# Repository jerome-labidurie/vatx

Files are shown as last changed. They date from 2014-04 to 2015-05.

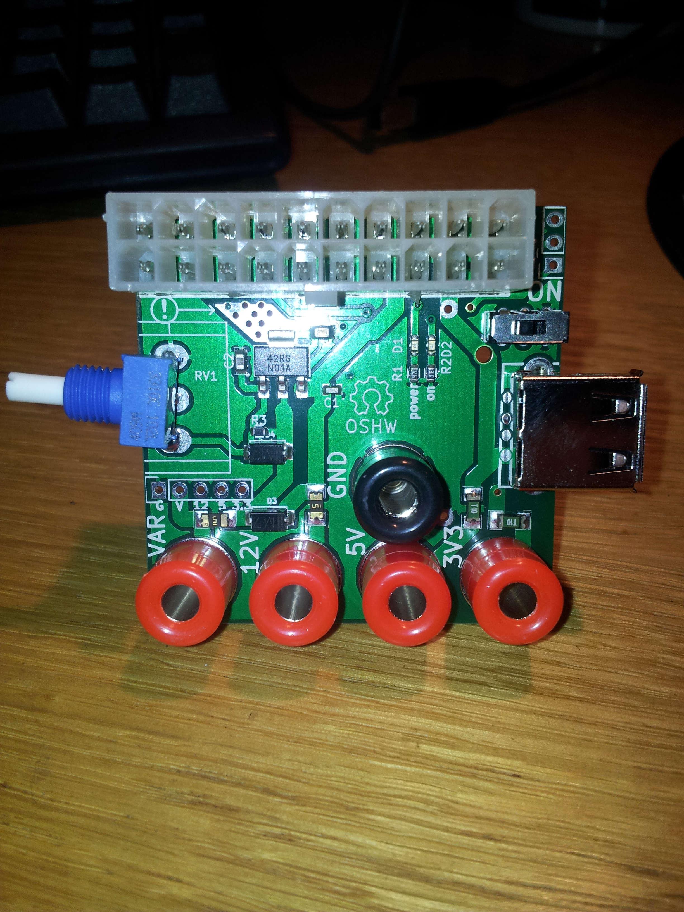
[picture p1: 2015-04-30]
pictures/vatx_proto_0_2.jpg

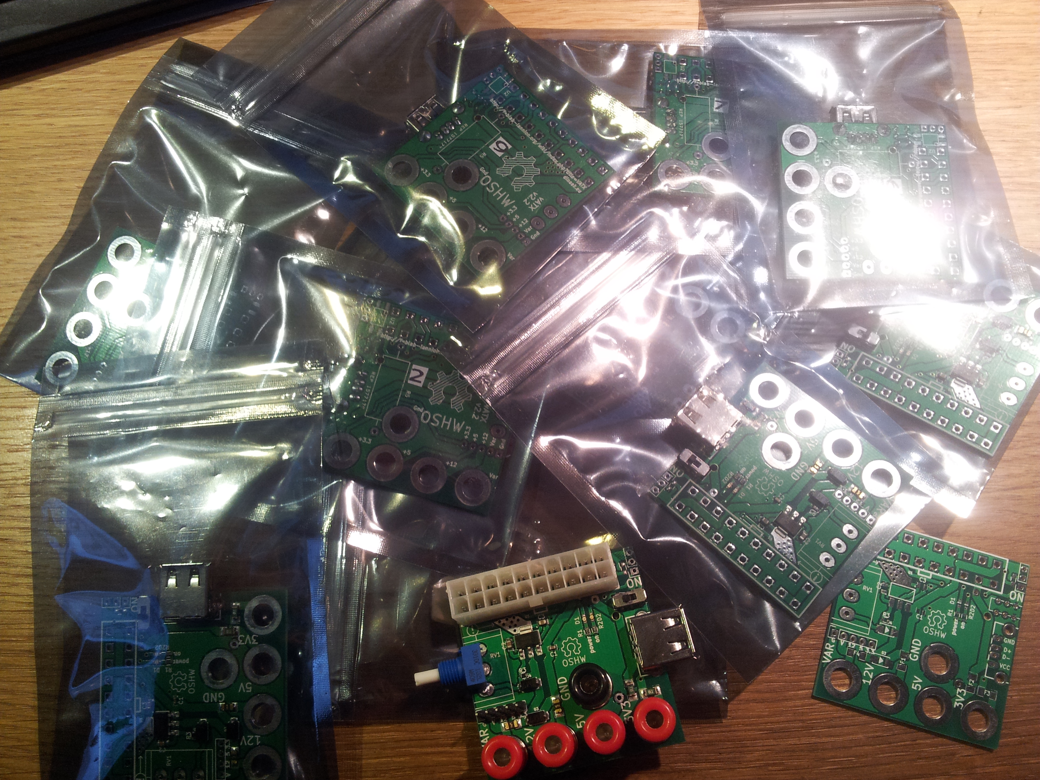
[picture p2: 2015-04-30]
pictures/vatx_proto_0_0.jpg

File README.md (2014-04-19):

Simple breakoutboard to use an ATX PSU as variable PSU
======================================================

* Goal is to use a un-modified ATX PSU.
* mostly one side-PCB for very simple creation
* Use banana plugs for every voltage
* Use LM317 for 1.5A variable voltage (~ 3-11V)
* USB connector for particular devices
* StandBy/Power leds
* OpenHardware CC:BY-SA http://creativecommons.org/licenses/by-sa/3.0/

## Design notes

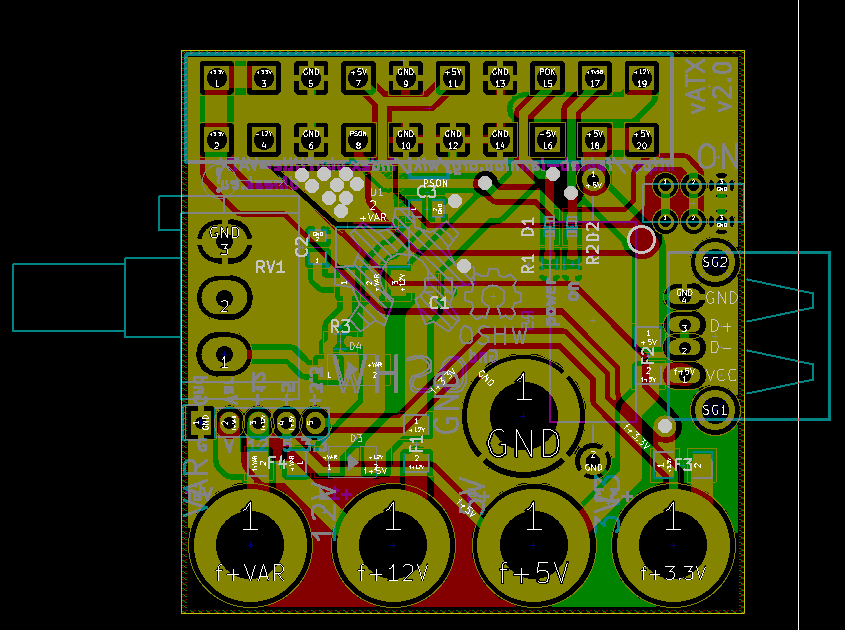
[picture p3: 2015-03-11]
pictures/vatx_pcb_v2.0.png

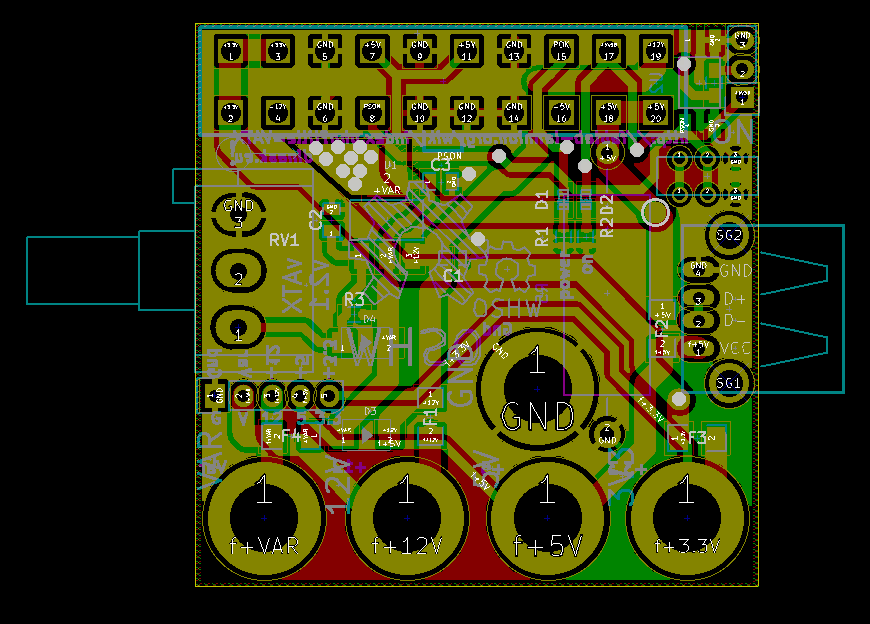
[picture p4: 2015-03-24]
pictures/vatx_pcb_v2.1.png

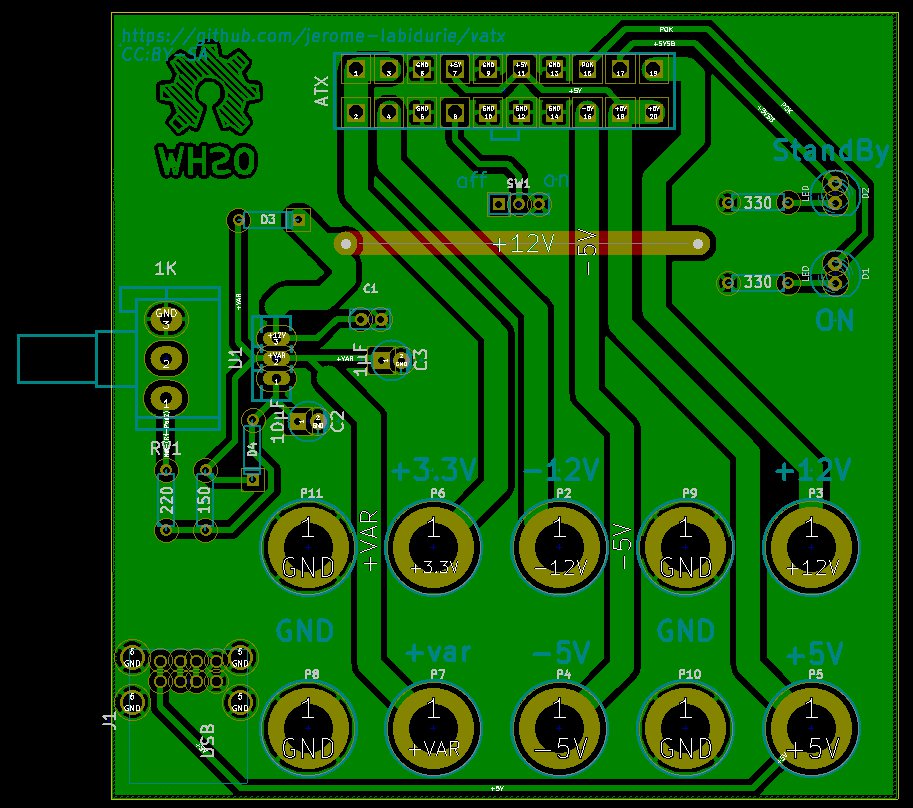
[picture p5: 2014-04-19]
pictures/vatx_pcb_v1.0.jpg

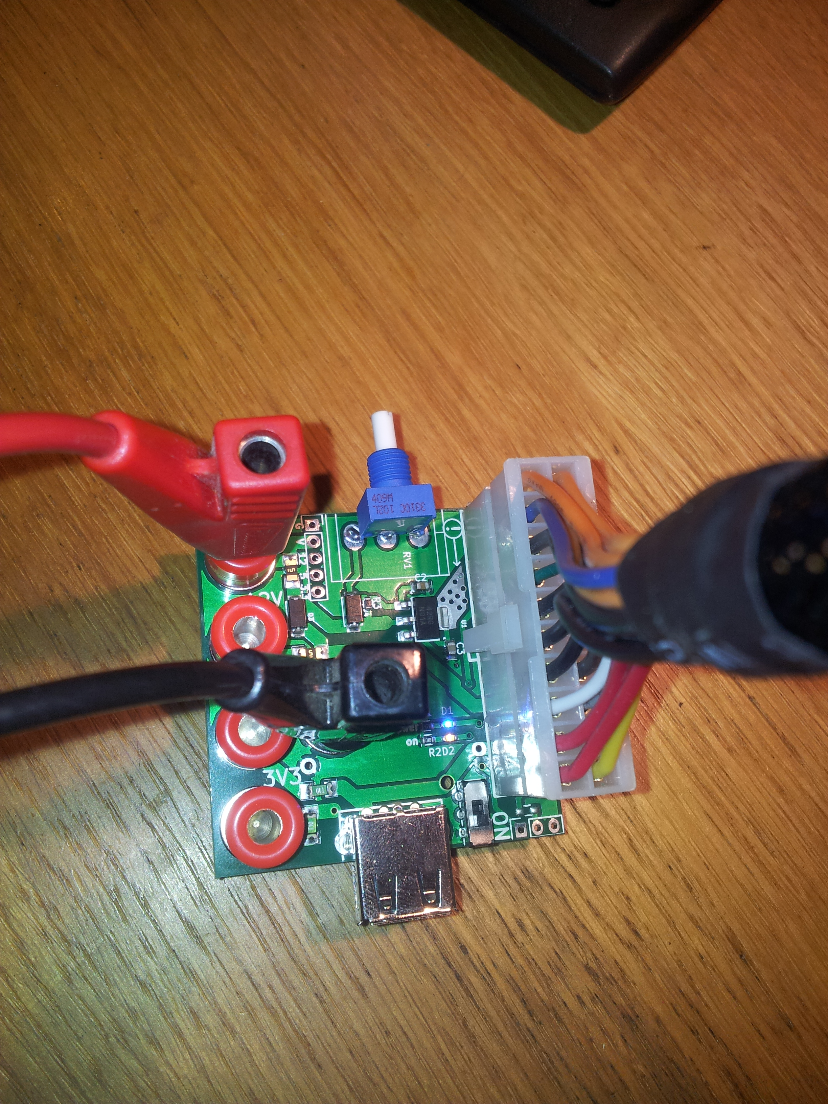
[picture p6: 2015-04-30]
pictures/vatx_proto_0_1.jpg

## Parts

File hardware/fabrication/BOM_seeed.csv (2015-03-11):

OPL SKU | Qty | Parts
310030006 | 1 | U1
320010007 | 1 | J1
0100020P1 | 1 | C1
0100080P1 | 1 | C2
0100440P1 | 1 | C3
0330060P1 | 1 | D1
0330050P1 | 1 | D2
307010013 | 2 | F1;F4
0900020P1 | 2 | F2;F3
301010088 | 1 | R1
0011090P1 | 1 | R2
301010090 | 1 | R3
0300040P1 | 2 | D3;D4
3010010P1 | 1 | SW1

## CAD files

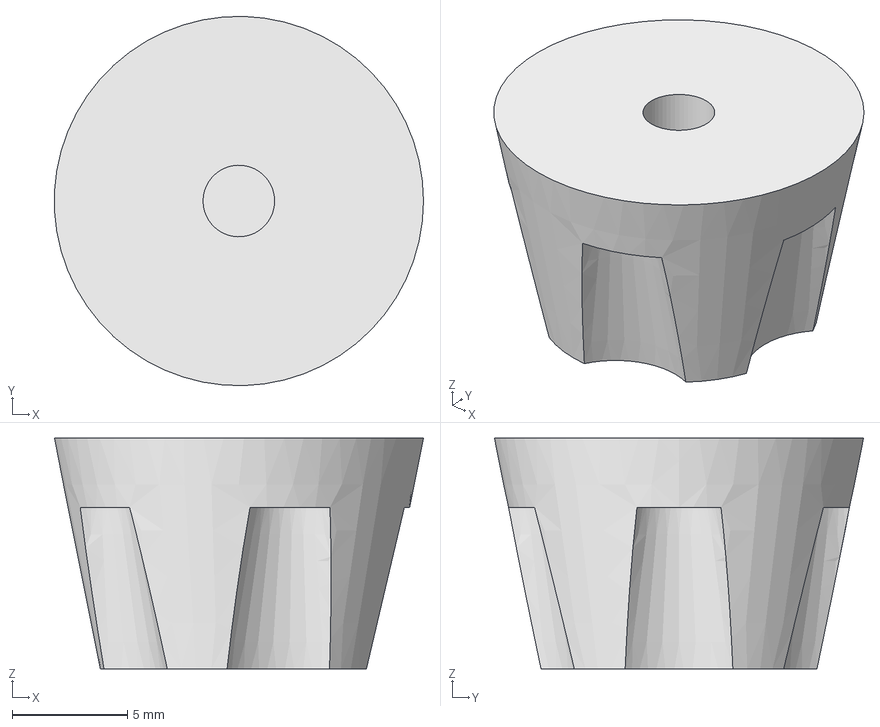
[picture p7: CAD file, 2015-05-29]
box/knob.fcstd
16.0 x 16.0 x 10.0 mm

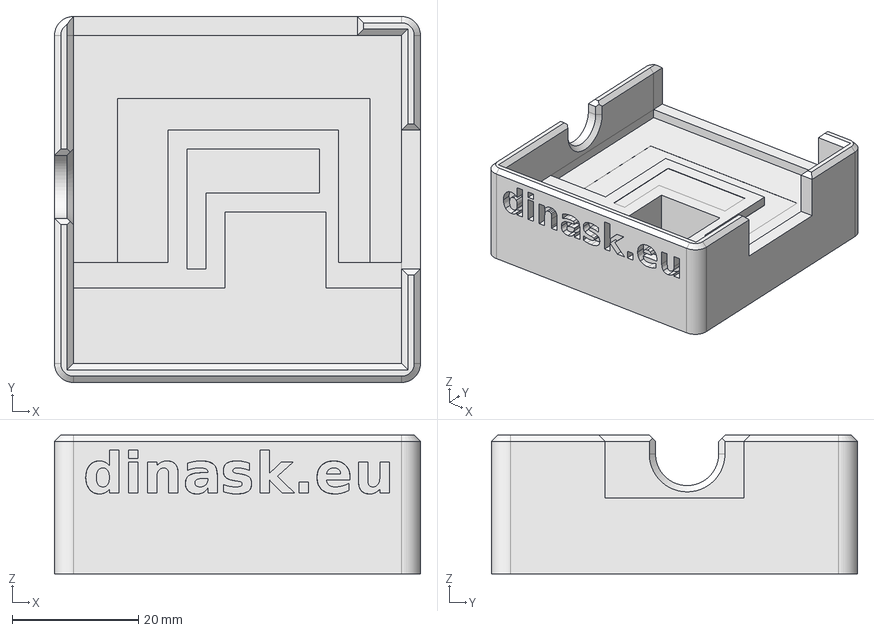
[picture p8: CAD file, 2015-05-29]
box/v2.2.FCstd
58.0 x 58.0 x 22.0 mm

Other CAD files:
box/knob.stl
box/v2.2.stl

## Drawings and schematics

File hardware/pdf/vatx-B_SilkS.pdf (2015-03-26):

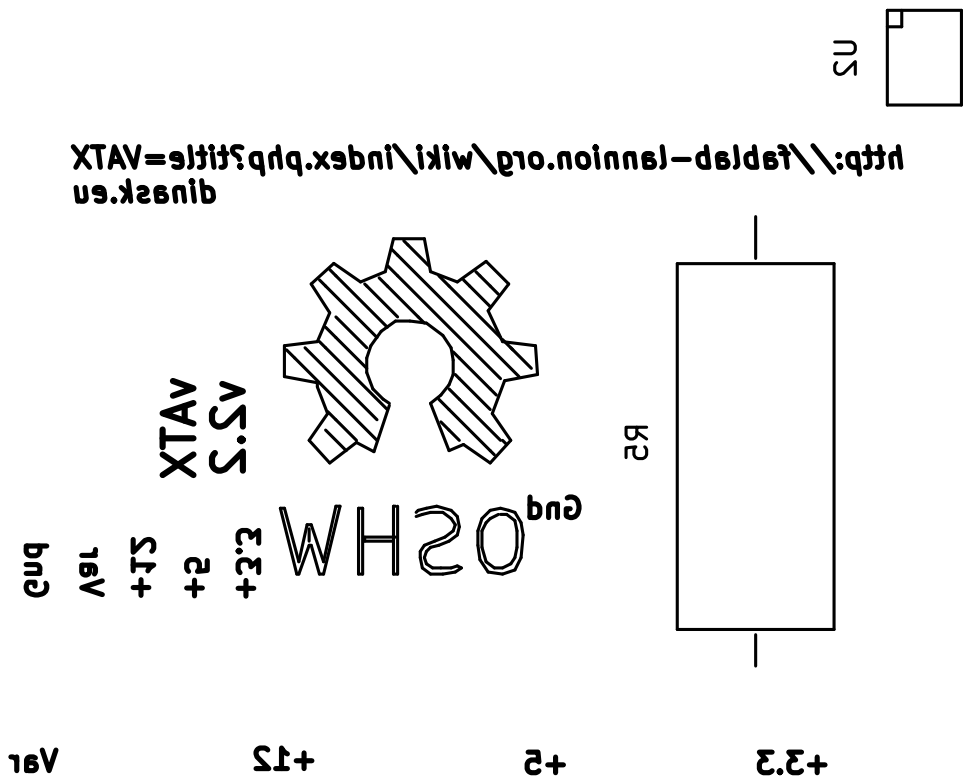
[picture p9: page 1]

http://fablab-lannion.org/wiki/index.php?title=VATX

Var +12 +5 +3.3 Gnd Gnd Var +12 +5+3.3 vATX v2.2

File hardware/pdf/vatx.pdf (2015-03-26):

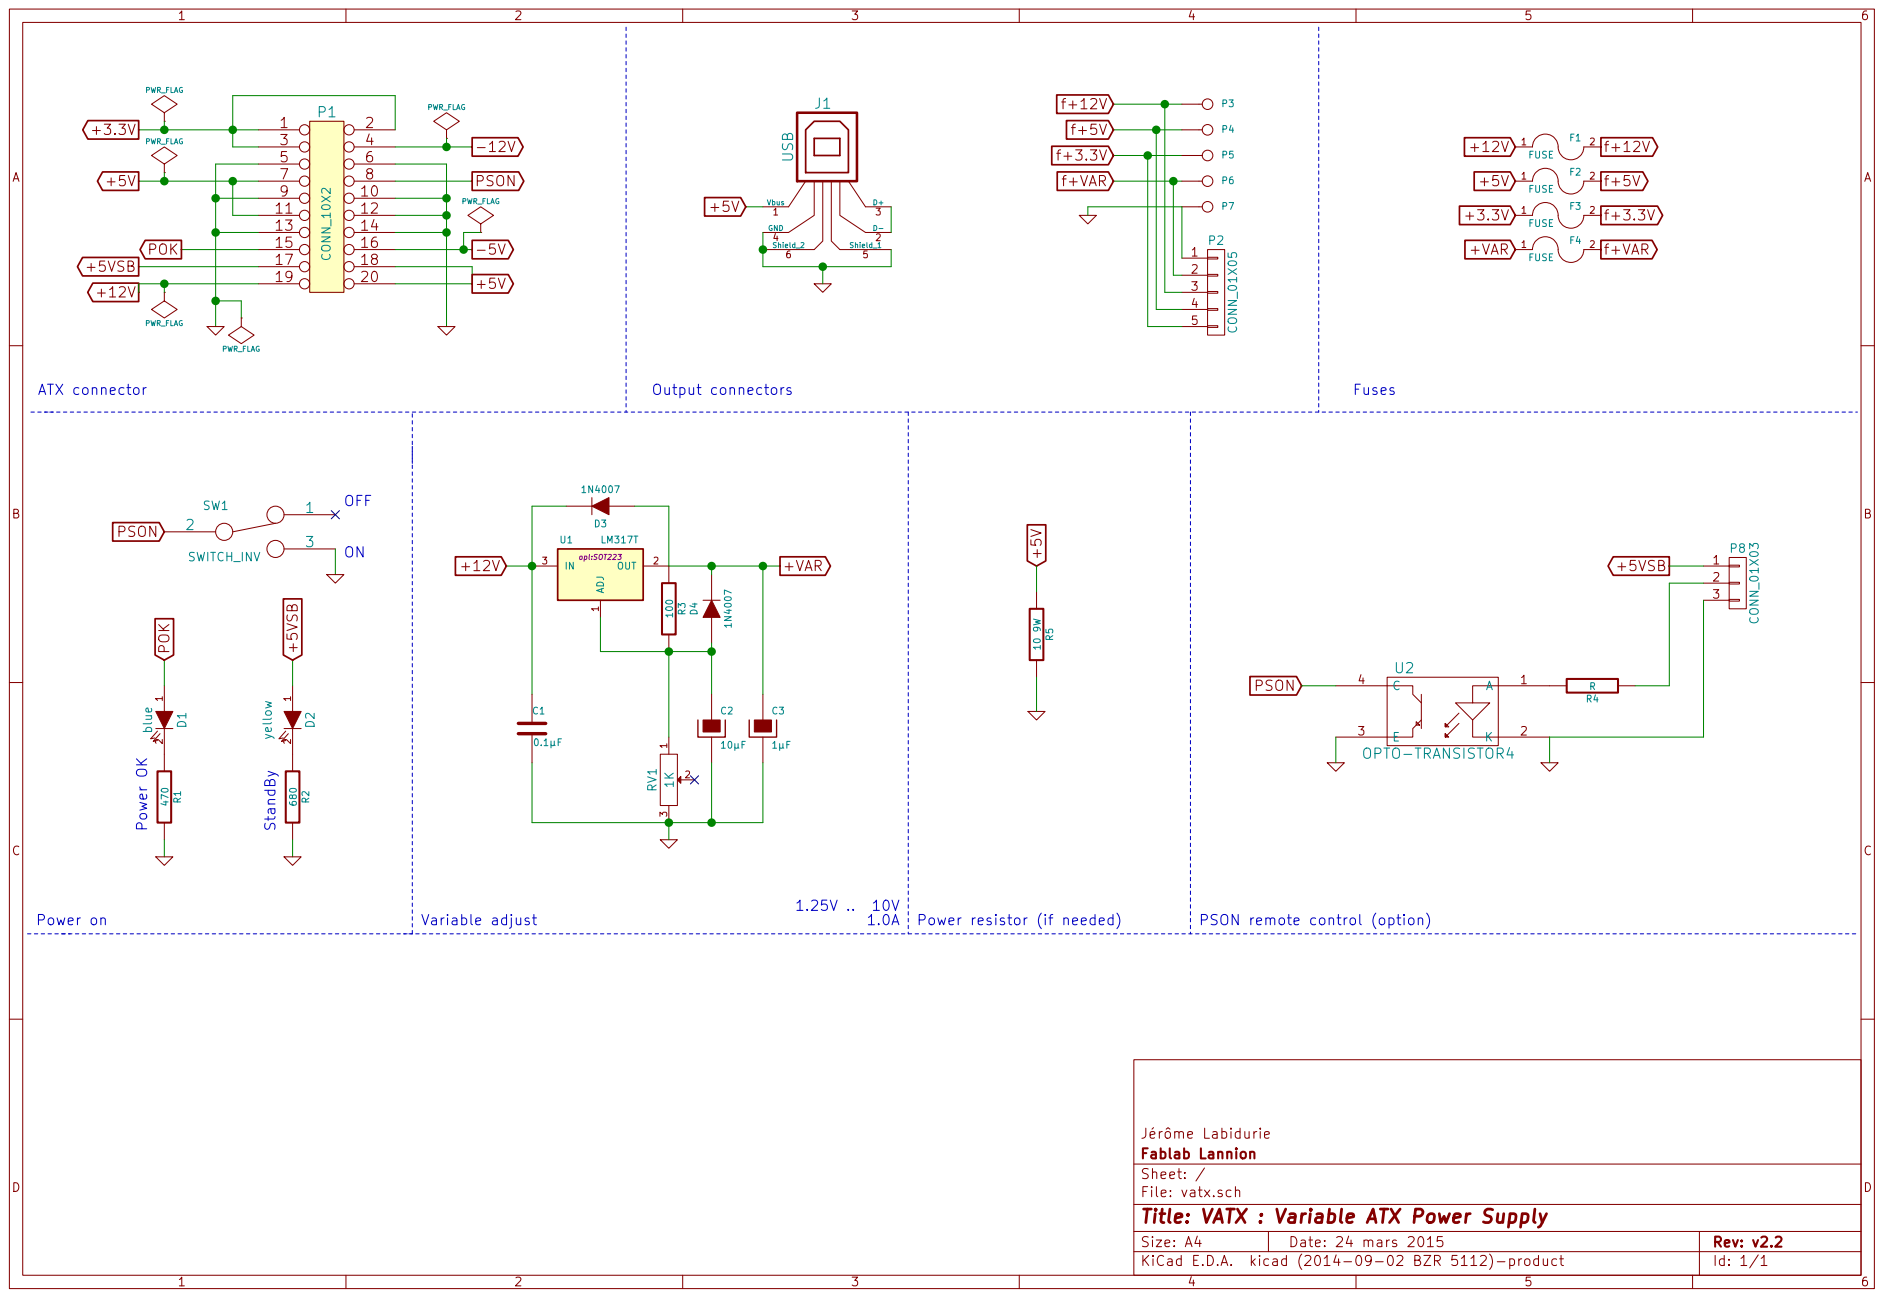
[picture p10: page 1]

1 2 D2 yellow 680 R2 +5VSB StandBy ADJ 1 OUT 2

1 2 D1 blue 470 R1 POK Power OK

Power resistor (if needed)

PSON remote control (option)

Jérôme Labidurie
File: vatx.sch Sheet: / Fablab Lannion

Id: 1/1 Title: VATX : Variable ATX Power Supply

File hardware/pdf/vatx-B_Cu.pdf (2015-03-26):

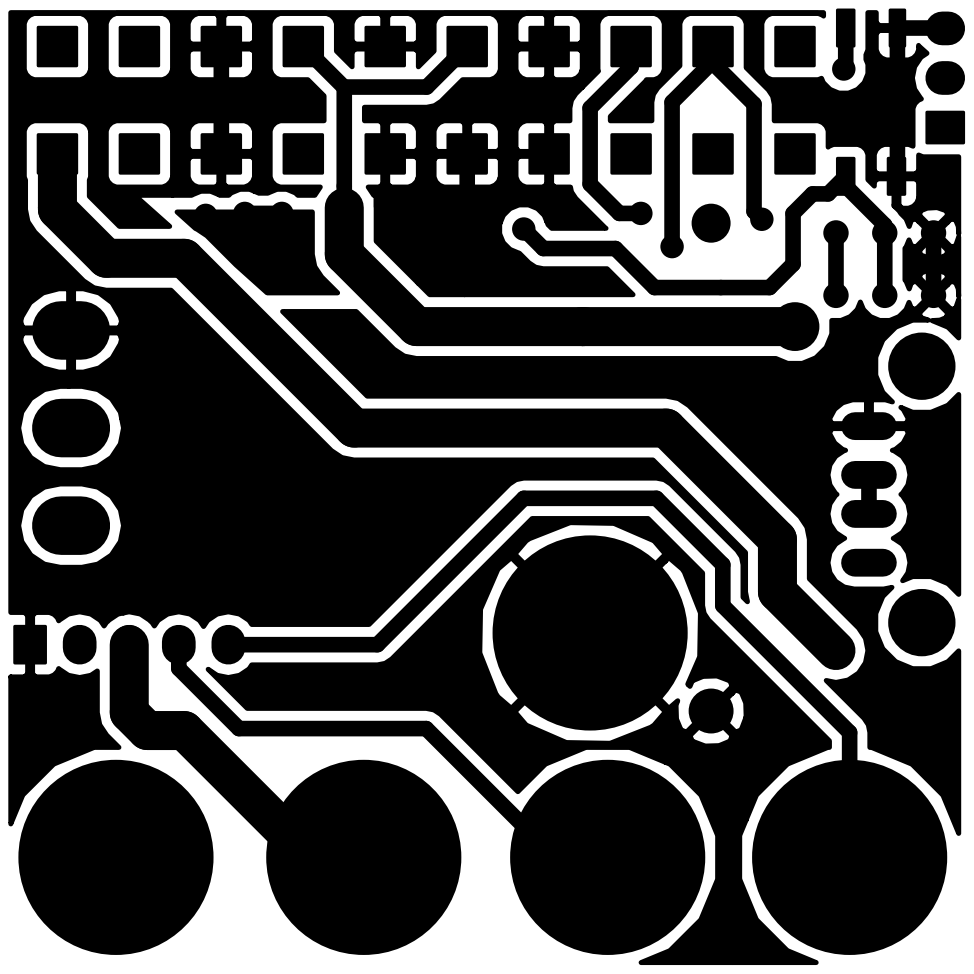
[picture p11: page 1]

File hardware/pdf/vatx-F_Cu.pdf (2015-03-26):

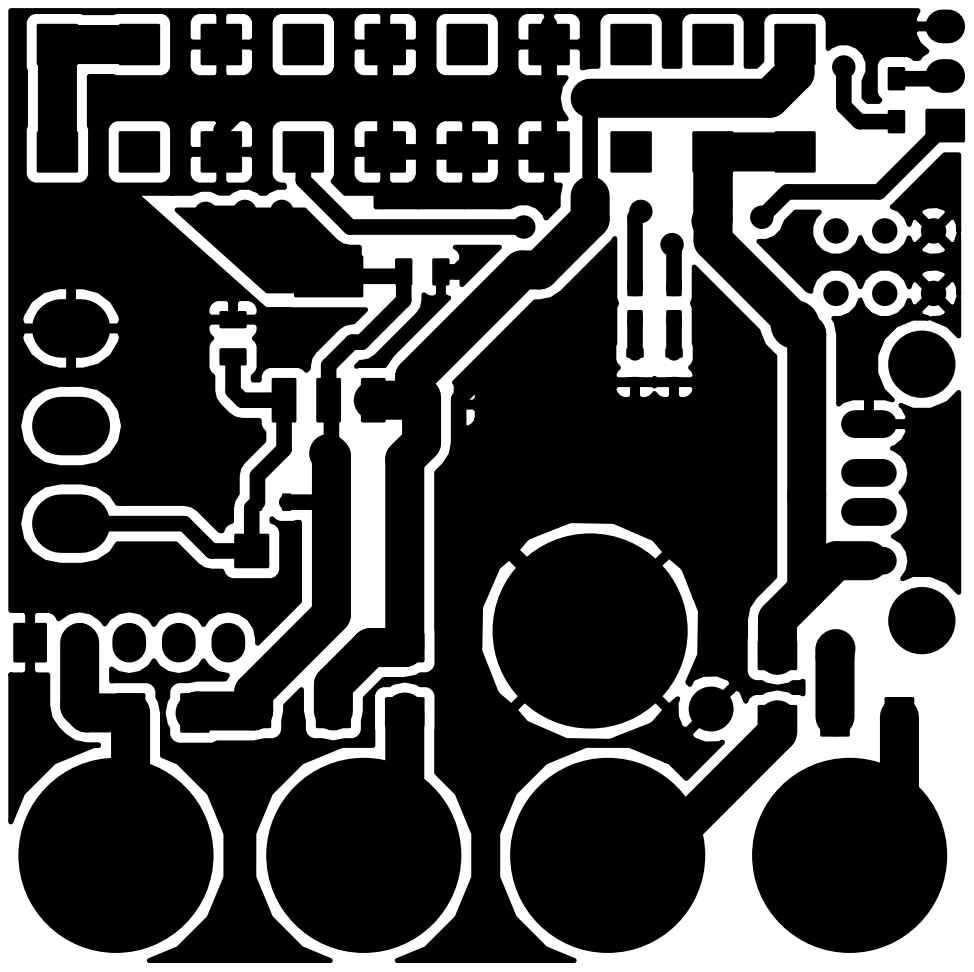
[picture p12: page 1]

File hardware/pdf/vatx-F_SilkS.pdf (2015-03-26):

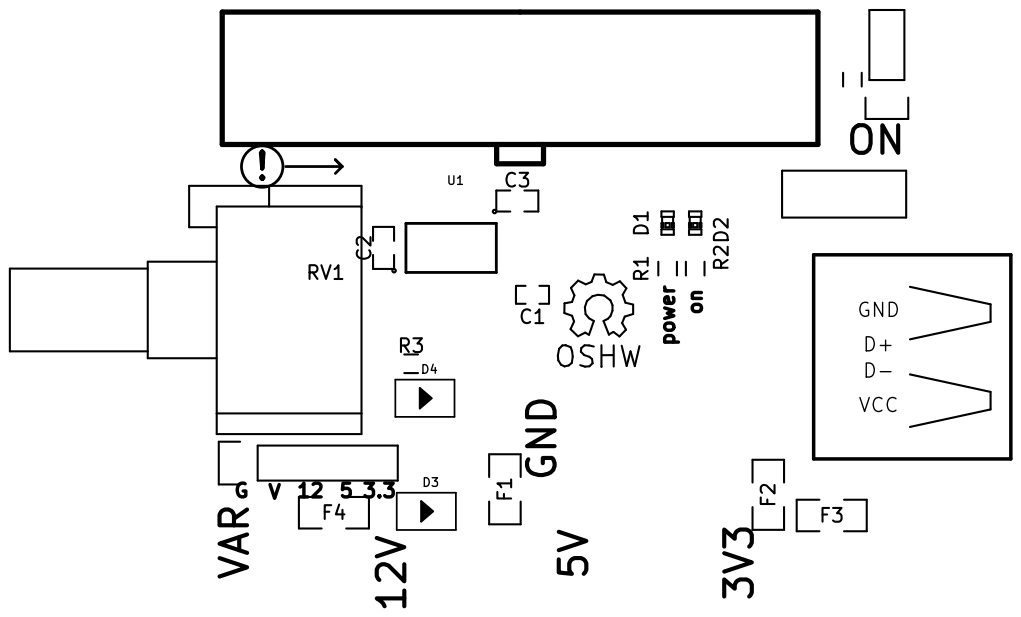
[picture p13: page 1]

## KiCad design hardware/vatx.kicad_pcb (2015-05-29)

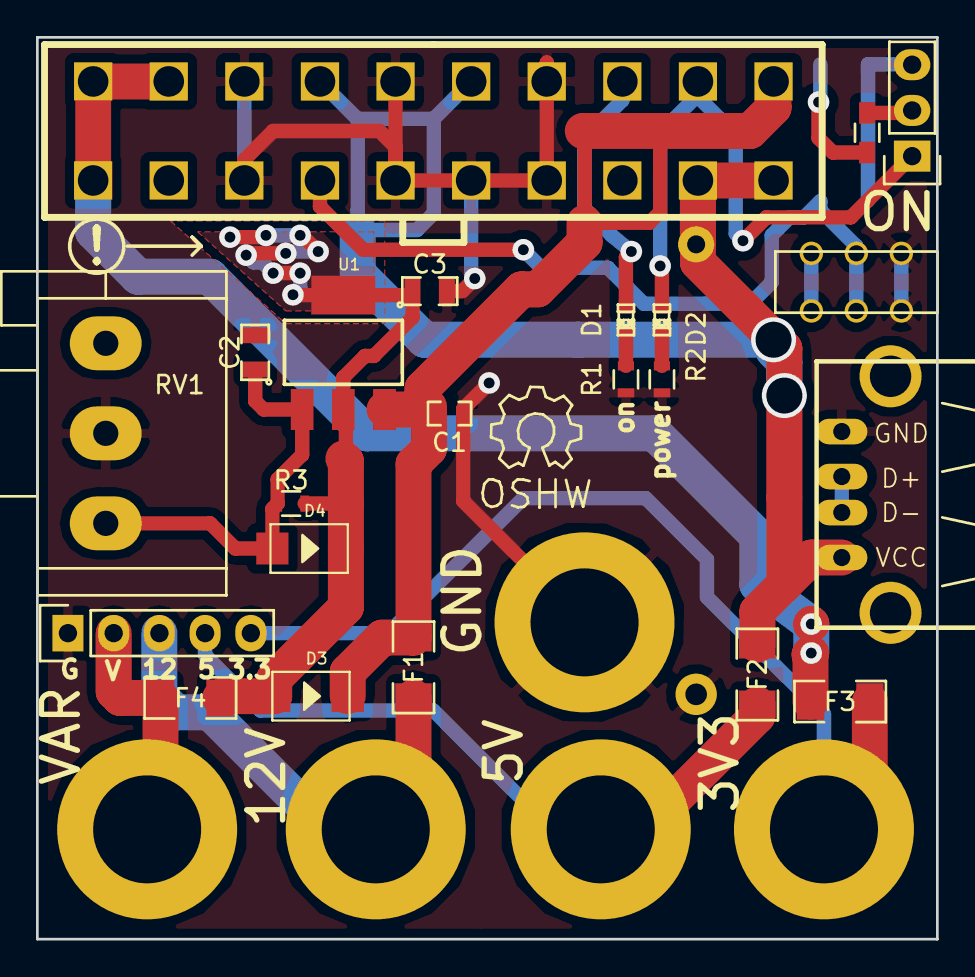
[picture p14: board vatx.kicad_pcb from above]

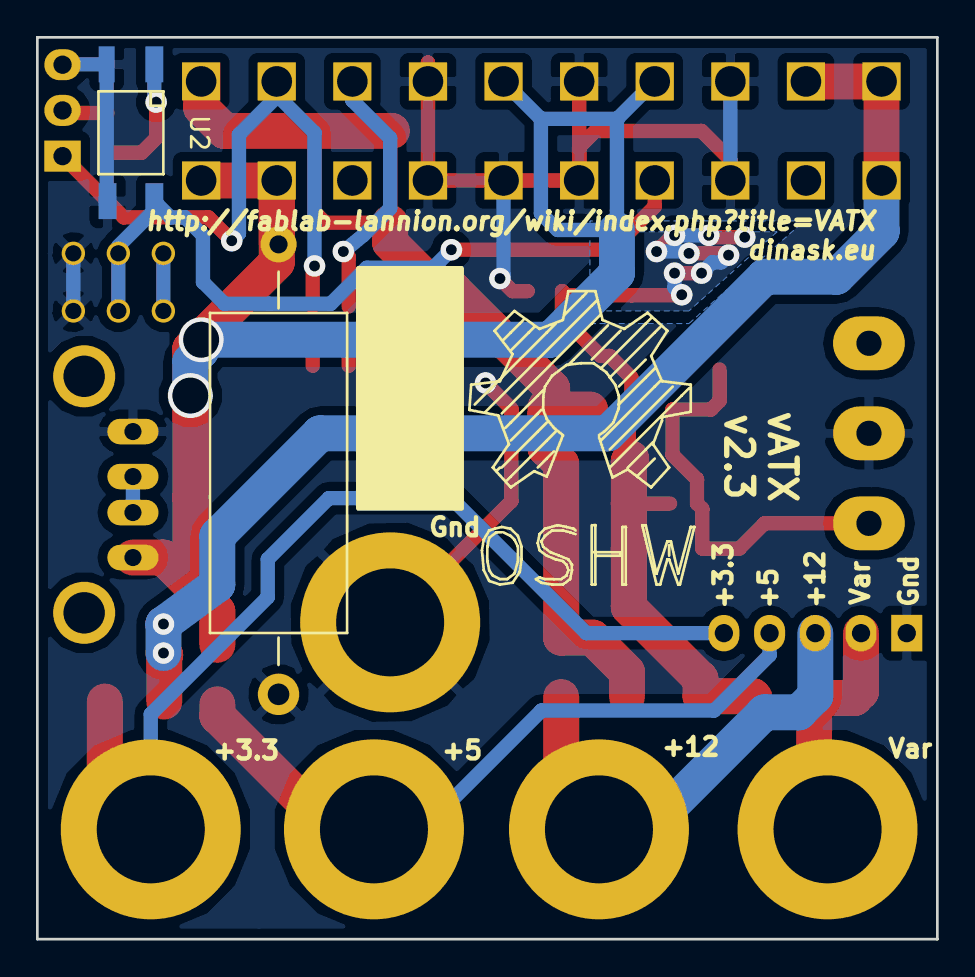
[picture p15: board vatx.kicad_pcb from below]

Board: 2 copper layers, 50.0 x 50.1 mm, 31 parts (3 on the bottom side), 18 nets.

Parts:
C1: 0.1µF; SMD-0603_c
C2: 10µF; SMD-0805
C3: 1µF; SMD-0805
D1: blue; LED-0603
D2: yellow; LED-0603
D3, D4: 1N4007; DO-214AC
F1, F2, F3, F4: FUSE; SMD-1206
J1: USB; 4P-2.0-90D
P1: CONN_10X2; ATX_NON_90DEG
P2: CONN_01X05; Pin_Header_Straight_1x05
P3, P4, P5, P6, P7: CONN_1; Banana_single_6mmDrill
P8: CONN_01X03; Pin_Header_Straight_1x03
R1: 470; R_0603
R2: 680; R_0603
R3: 100; R_0603
R4: R; R_0603_HandSoldering
R5: 10 9W; Resistor_Horizontal_RM25mm
RV1: 1K; Potentiometer_Alps-RK16-single_largePads
SW1: SWITCH_INV; TS-1101F
Symbol_OSHW-Logo_SilkScreen: VAL**; Symbol_OSHW-Logo_SilkScreen
Symbol_OSHW-Logo_SilkScreen_BIG: VAL**; Symbol_OSHW-Logo_SilkScreen_BIG
U1: LM317T; SOT223
U2: OPTO-TRANSISTOR4; Optocoupler_SMD_HandSoldering_KPC357_LTV35x_PC357_SingleCha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

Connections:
+3.3V: F3.1, P1.1, P1.2, P1.3
+5V: F2.1, J1.1, P1.7, P1.11, P1.18, P1.20, R5.1
+5VSB: D2.1, P1.17, P8.1
+12V: C1.1, D3.2, F1.1, P1.19, U1.3
+VAR: C3.1, D3.1, D4.2, F4.1, R3.1, U1.2
GND: C1.2, C2.2, C3.2, J1.4, P1.5, P1.6, P1.9, P1.10, P1.12, P1.13, P1.14, P2.1, P7.1, P8.3, R1.2, R2.2, R5.2, RV1.2, SW1.3, U2.2, U2.3
unnamed: C2.1, D4.1, R3.2, RV1.1, U1.1
unnamed: D1.2, R1.1
unnamed: D2.2, R2.1
unnamed: J1.2, J1.3
unnamed: P8.2, R4.1
unnamed: R4.2, U2.1
POK: D1.1, P1.15
PSON: P1.8, SW1.2, U2.4
f+3.3V: F3.2, P2.5, P5.1
f+5V: F2.2, P2.4, P4.1
f+12V: F1.2, P2.3, P3.1
f+VAR: F4.2, P2.2, P6.1

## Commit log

2014-04-19 first import
    [vatx.dsn, vatx.kicad_pcb, vatx.sch]
2014-04-19 Add fabrications files/pdf
    [vatx.kicad_pcb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]
2014-09-28 Mounting holes
    [vatx.kicad_pcb]
2014-12-19 Move to a smaller board * remove load resistor * remove -5 / -12 * 50x50mm pcb * SMD components for seeedstudio OPL
    TODO:
    * switch footprint
    * check diodes footprint
    * silkscreen
    [vatx.kicad_pcb, vatx.sch]
2015-03-09 Short between D+/D- to be an USB DCP http://www.maximintegrated.com/en/app-notes/index.mvp/id/4803
    [vatx.kicad_pcb, vatx.sch]
2015-03-09 LM317 heatsink
    [vatx.kicad_pcb]
2015-03-10 room for 24pins ATX connector seeed opl switch footprint seeed opl usb A footprint fused +5V for usb leds on/power labels paste for heatsink
    [vatx.kicad_pcb, vatx.sch]
2015-03-10 +VAR vias
    [vatx.kicad_pcb]
2015-03-10 scheme/pcb version again via for heatsink
    [vatx.kicad_pcb, vatx.sch]
2015-03-10 Add power resistor some PSU need that to deliver current
    [vatx.kicad_pcb, vatx.sch]
2015-03-11 Set seeed opl diode footprint
    [vatx.kicad_pcb]
2015-03-11 Update +VAR : remove R4 R1/R2 values updated for choosen leds Seeed BOM
    [BOM_seeed.csv, vatx.kicad_pcb, vatx.sch]
2015-03-11 Add pin-header for every voltage
    [vatx.kicad_pcb, vatx.sch]
2015-03-24 led doc
2015-03-24 scheme for optional PSON control
    [vatx.sch]
2015-03-24 pcb for optional PSON control
    [vatx.kicad_pcb, vatx.sch]
2015-03-25 Remove fuse for 5V usb
    [vatx.kicad_pcb, vatx.sch]
2015-03-25 Fabrication files for v2.2
    [vatx-B_Cu.gbl, vatx-B_Mask.gbs, vatx-B_Paste.gbp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]
2015-04-30 3D file for box 1st batch pictures
    [v2.2.FCstd, v2.2.stl]
2015-05-06 box bug hole for gnd plug
    [v2.2.FCstd, v2.2.stl]
2015-05-12 Corrected box
    [v2.2.FCstd, v2.2.stl]
2015-05-18 3d model for potentiometer knob
    [knob.fcstd, knob.stl]
2015-05-18 V2.2 bugfix & enhancement * potentiometer connection * power/on silkscreen * more 0.8 traces for power traces (+12V, +5V) * more via for power traces (+5V, +3.3V)
    [vatx.kicad_pcb, vatx.sch]
2015-05-29 Add silk rectangle for serial #
    [vatx.kicad_pcb]
2015-05-29 Simplify 3D box design to speedup printing
    [v2.2.FCstd, v2.2.stl]
2015-05-29 Correction of pot shaft diameter
    [knob.fcstd, knob.stl]
